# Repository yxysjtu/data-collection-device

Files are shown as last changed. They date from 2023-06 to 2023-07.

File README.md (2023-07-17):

# Datalogger

This is a picture of the device supporting low frequency sensor data-logging with STM32F103RGT6.
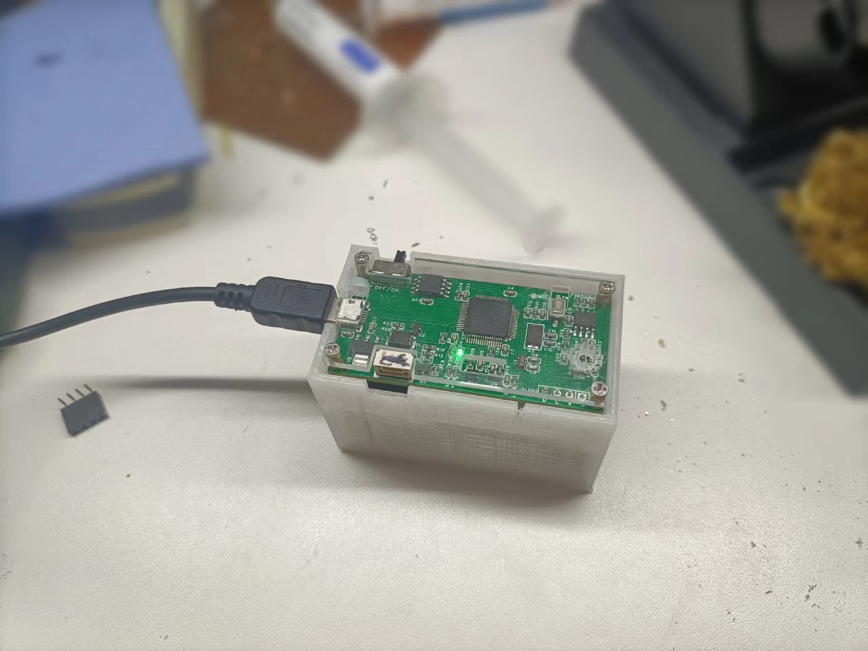
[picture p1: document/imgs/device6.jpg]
 
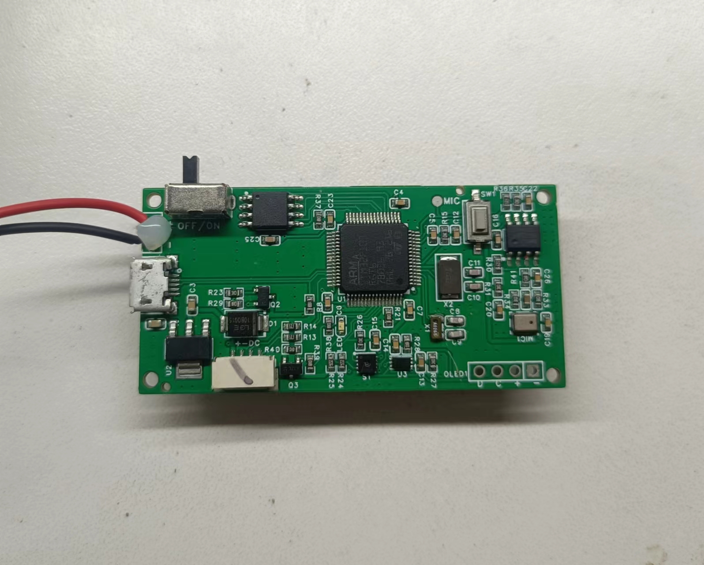
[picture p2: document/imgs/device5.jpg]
 

Core functions:
* periodically collect environment data such as temperature, humidity, light intensity and sound intensity (the sampling period can be configured in software user-interface)
* log data to an external flash (16MB, more than enough memory for 1 year usage)
* provide user-friendly interface to configure the device and retrive data (simulate a USB disk to easily store and get data as files in .csv format, using python script to write configuration info into the device)

Specs:
* 2 AA batteries with 6000h life expectancy. (suppose 50uA in standby mode and 40mA in active mode, the logging time is 2s, 1h sampling period, 1000mAh battery)
* can store up to 45000 records before running out of battery charge
* support measurement of sound(35-100dB), light(0-65535lux), temperature(0-85 degree in celsius), humidity(0-100%)

How to use:
1. Open the switch on the device and it will start periodically collecting data.
2. If you need to configure the time and sampling-period of the device, plug in the micro-usb cable, run config.py and input sampling period. Unplug the cable, and the device will read the configuration info and update its time according to the local time of your computer, the LED will double blink indicating config success, and set up alarm time before going to standby mode.
3. If you need to get the data, plug in the micro-usb cable. The device should be recognized by your computer as USB Mass Storage Device. The data is stored in csv format and you can easily copy it to your computer for further data processing.
4. If the LED is constantly blinking, that is suggesting low battery.

* USB disk interface
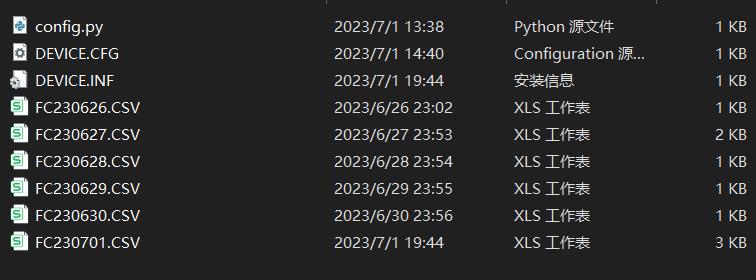
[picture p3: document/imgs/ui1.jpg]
USB disk
 
* Configuration interface
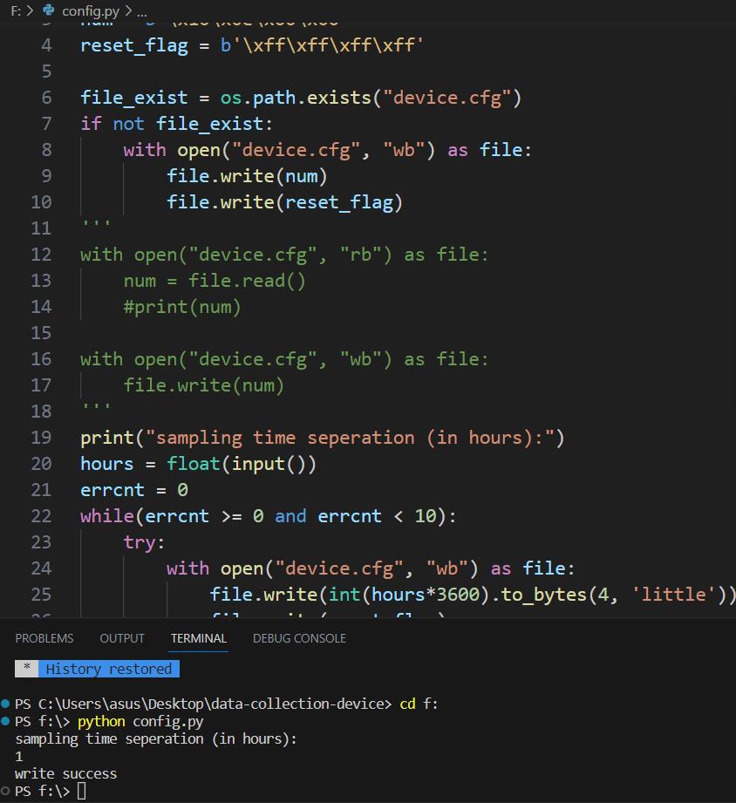
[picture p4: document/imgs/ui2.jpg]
config UI
 
* Data format
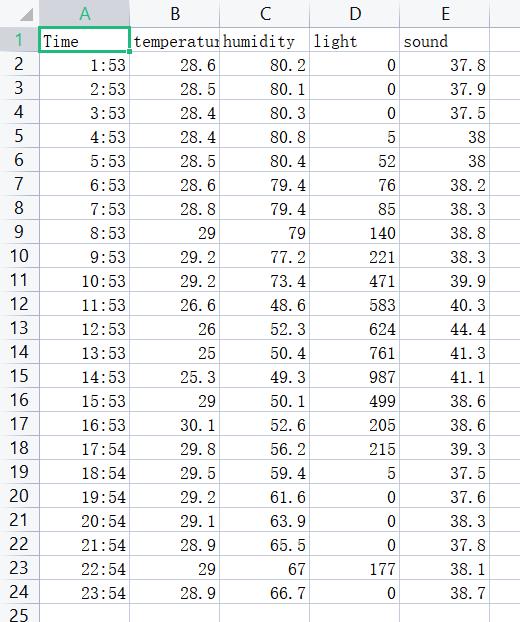
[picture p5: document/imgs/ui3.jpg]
data format
 

## Hardware Design
### Schematic
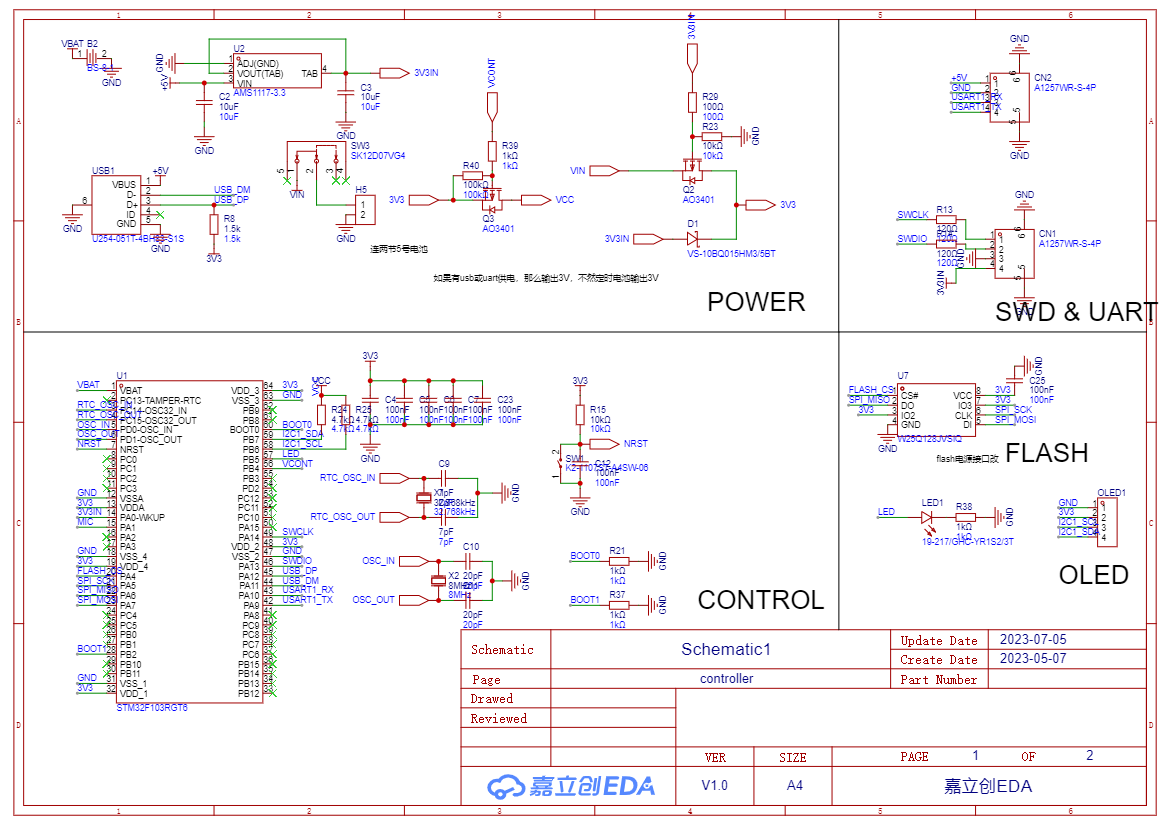
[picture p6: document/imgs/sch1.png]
Controller
 
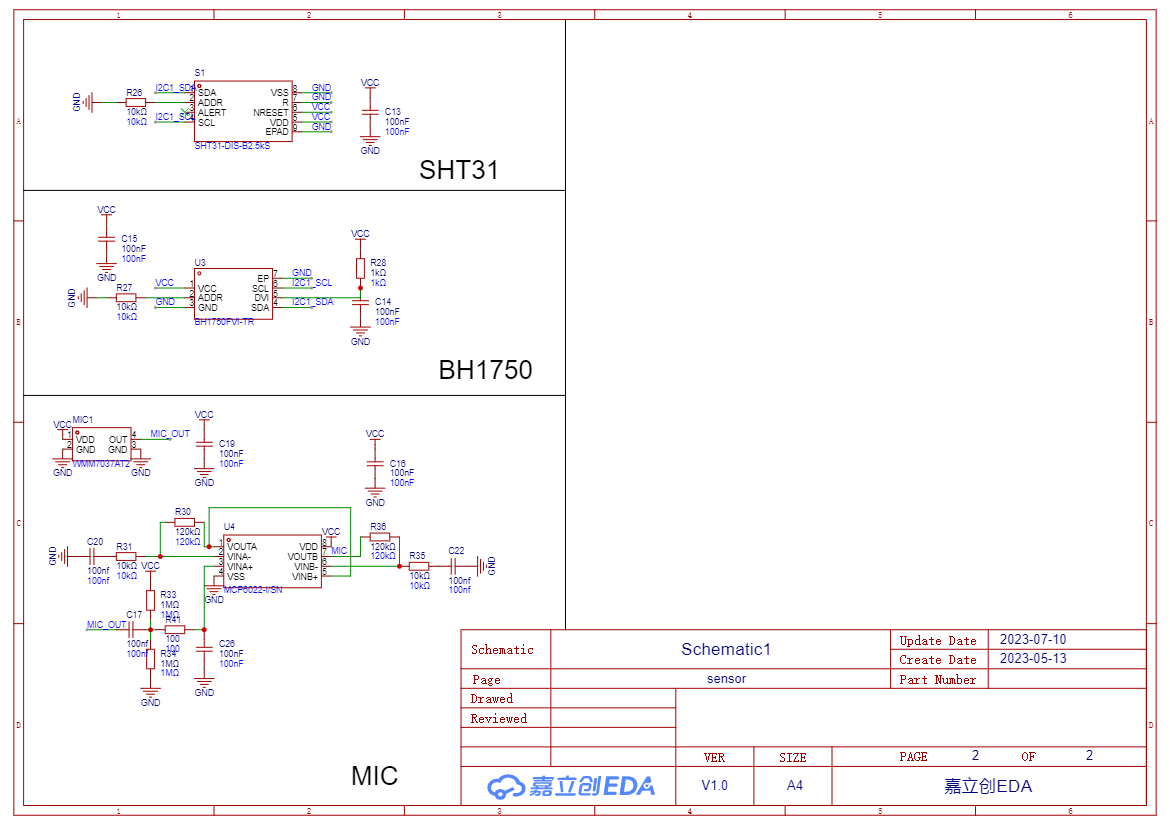
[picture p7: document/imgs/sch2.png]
Sensors
 

(notice: choose 7pf 32.768khz crystal oscillator for stable oscillation)

### PCB
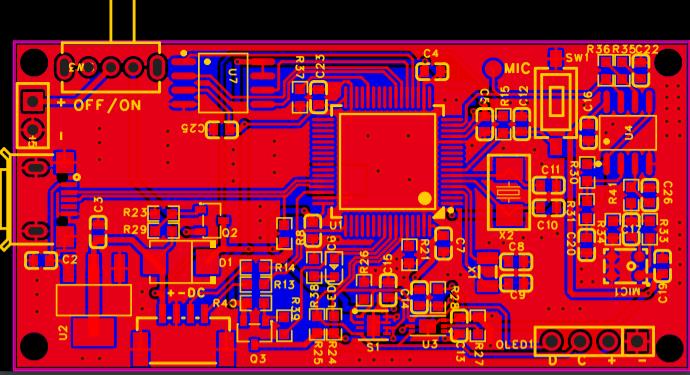
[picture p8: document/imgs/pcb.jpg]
PCB
 

### Mechanical Design
* Front panel using laser cutting PMMA
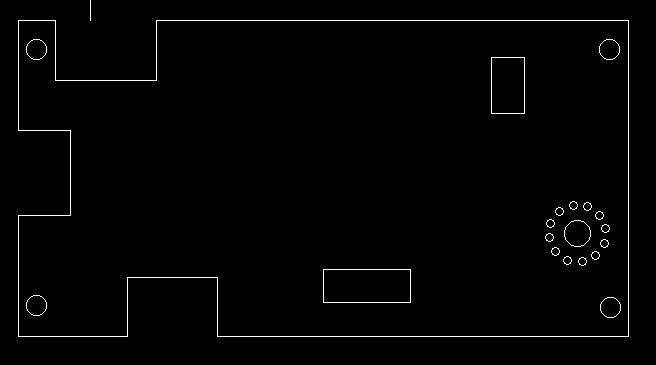
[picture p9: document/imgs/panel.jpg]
panel
 
* 3D printed body part and bottom cover
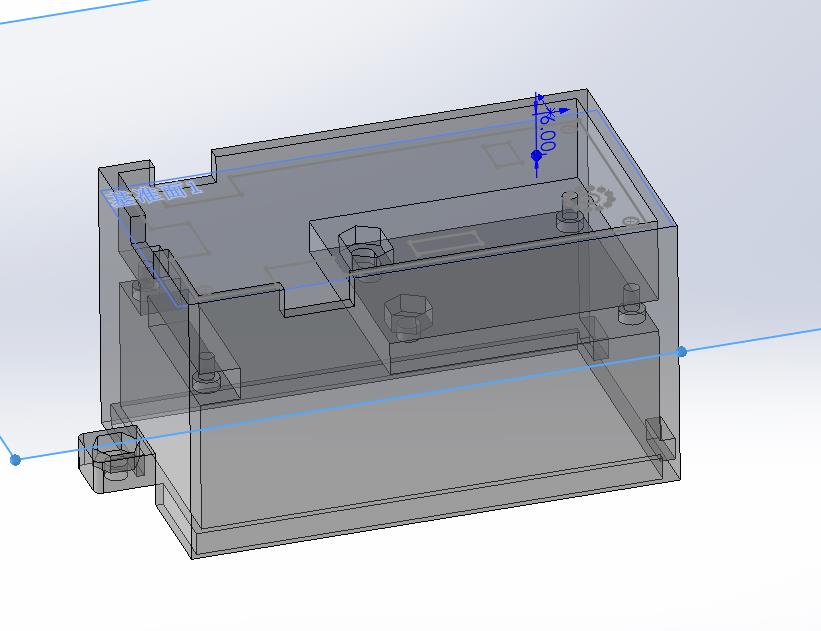
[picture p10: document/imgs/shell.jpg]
body
 
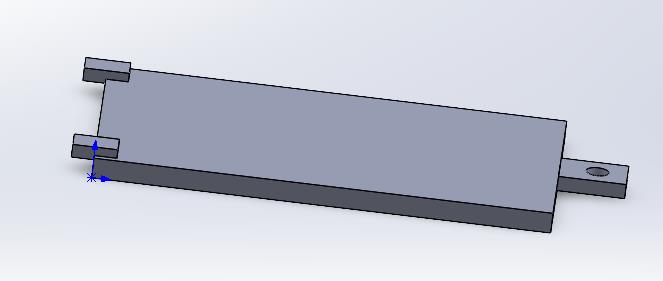
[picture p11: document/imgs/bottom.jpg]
bottom
 

## Firmware
The project is developed using CubeMX and KEIL, using STM32 HAL library.

The main code is in /code/run.h

All custom library is in /code/lib/

The project file is in /firmware/

## Background
For background on / motivation for this project, please see https://opendeved.net/programmes/ilce-in-tanzania/.

Reference: (same project with different design) https://github.com/bablokb/pcb-pico-datalogger#pico-datalogger-with-integrated-power-management

## License
This work is licensed under CC-BY-4.0.

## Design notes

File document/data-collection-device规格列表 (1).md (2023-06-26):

# 定时采样传感器规格列表

### 修订历史
|  | 时间| 备注|
| --- | --- | --- |
| 1 | 2023/6/23 | 添加产品说明与测量精度|
| 2 | 2023/6/26 | 根据实际测量修改产品尺寸，添加实物图片，补充使用方法，加入注意事项 |

### 产品说明
| 名称 | 规格|
| --- | --- |
| 产品尺寸 | 64.8X37.9X38.8 (mm X mm X mm) | 
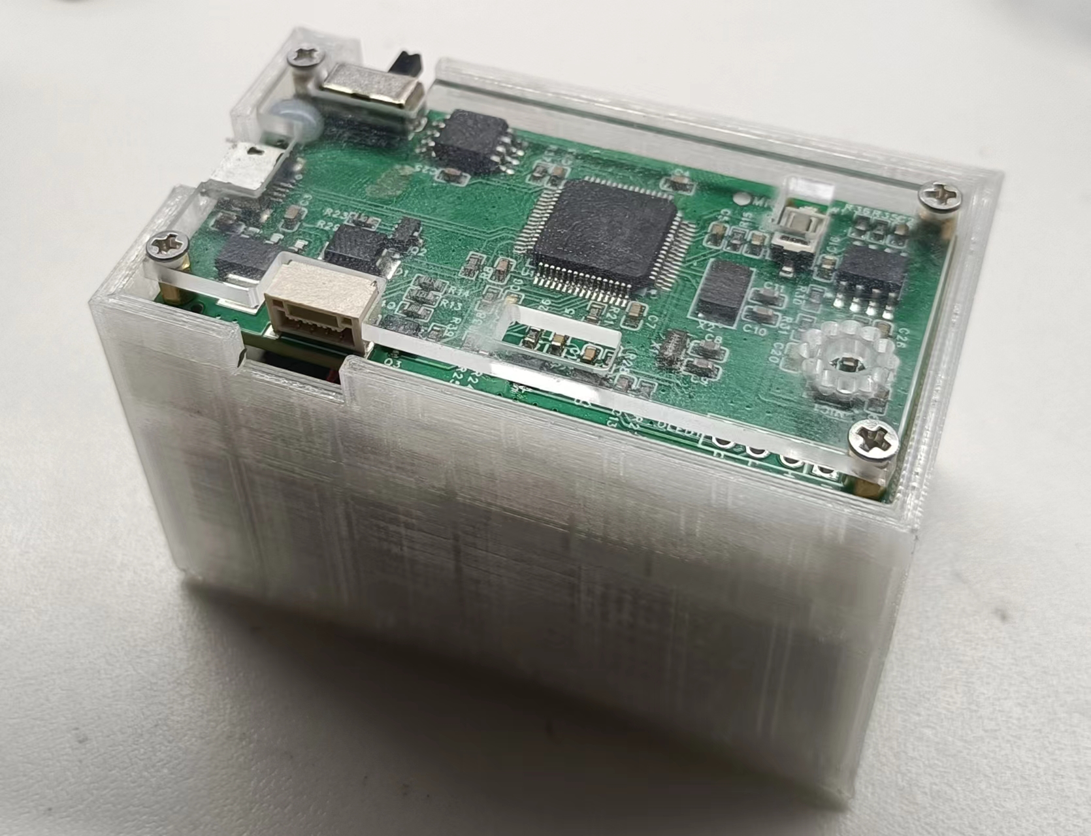
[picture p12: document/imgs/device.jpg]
输入图片说明
| 实物图片 | |
| 电源 | 2节5号电池 + 1节纽扣电池CR2032 |
| 使用寿命 | 6000h（以电池电量800mAh，采样间隔1h计算，平均消耗电量0.133mAh/h）
| 功能 | 以指定频率测量光照，温度，湿度，声强数据，并记录，可以以USB接口读出数据|
| 使用方法 | 初始先用USB线插入电脑，设备作为U盘接入电脑，运行U盘内的config.py(需要电脑已安装python)，输入每几小时采样一次，设备则会存下当前本机时间进行校准设备时间，以及存下采样时间间隔。安装电池，打开开关，设备则会以给定时间间隔进行采样，并把数据以csv的格式进行存储。每日存储一个csv文件，名称为FCyymmdd.CSV，如FC230601.CSV.|
|注意事项| 1.在校准时间成功后设备指示灯会闪烁一下; 2.在电池电压不足时设备指示灯会在USB电源插入后频闪.|

### 测量精度
（实验室环境下测试）
| 指标 | 精度|
| --- | --- |
|光照| +-10% (0~65535lux) |
| 温度 | +-3摄氏度 (0~85度) |
| 湿度 | +-2% (0~100%)|
| 声强 | +-3dB (35~100dB)|

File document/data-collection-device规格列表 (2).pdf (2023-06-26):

# 定时采样传感器规格列表

### 修订历史

| 时间 | 备注
1 | 2023/6/23 | 添加产品说明与测量精度
2 | 2023/6/26 | 根据实际测量修改产品尺⼨，添加实物图⽚，补充使⽤⽅法，加⼊注意事项

### 产品说明

名 称 | 规格
产 品 尺 ⼨ | 64.8X37.9X38.8 (mm X mm X mm)

实
物
图
⽚

电
源

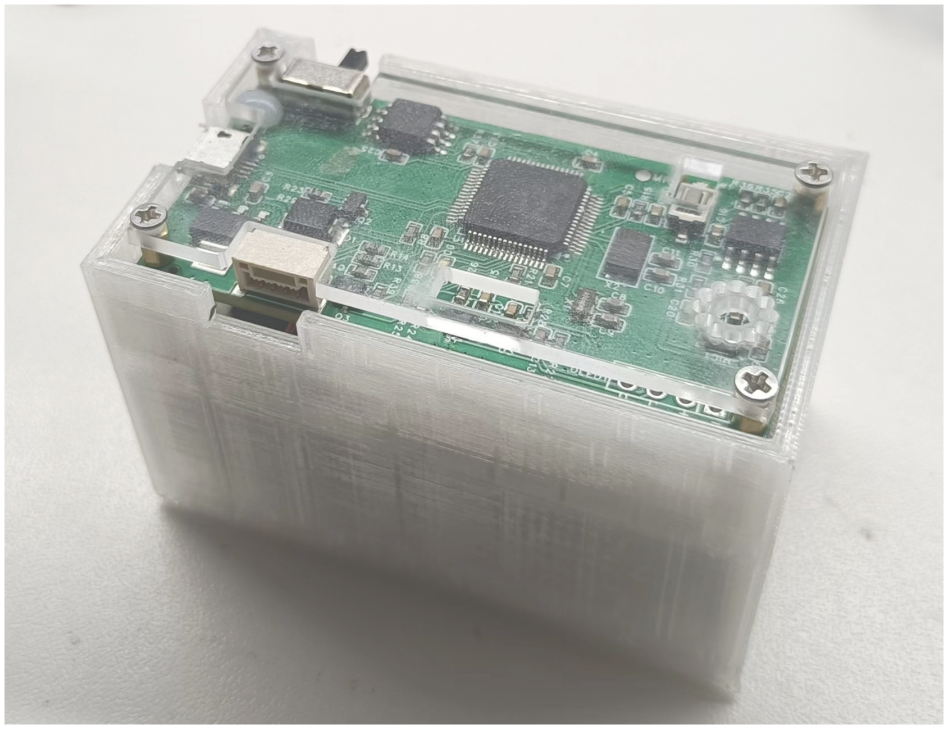
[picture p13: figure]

2节5号电池 + 1节纽扣电池CR2032

名 称 | 规格
使 ⽤ 寿 命 | 6000h（以电池电量800mAh，采样间隔1h计算，平均消耗电量0.133mAh/h）
功 能 | 以指定频率测量光照，温度，湿度，声强数据，并记录，可以以USB接⼝读出数据
使 ⽤ ⽅ 法 | 初始先⽤USB线插⼊电脑，设备作为U盘接⼊电脑，运⾏U盘内的config.py(需要电脑已安装 (http://xn--uconfig-3p9ku36y7xag81lw3s.py) python)，输⼊每⼏⼩时采样⼀次，设备则会存下当前本机时间进⾏校准设备时间，以及存下采样 时间间隔。安装电池，打开开关，设备则会以给定时间间隔进⾏采样，并把数据以csv的格式进⾏ 存储。每⽇存储⼀个csv⽂件，名称为FCyymmdd.CSV，如FC230601.CSV.
注 意 事 项 | 1.在校准时间成功后设备指⽰灯会闪烁⼀下; 2.在电池电压不⾜时设备指⽰灯会在USB电源插⼊后 频闪.

### 测量精度

（实验室环境下测试）

指标 | 精度
光照 | ±10% (0~65535lux)
温度 | ±3摄⽒度 (0~85度)
湿度 | ±2% (0~100%)
声强 | ±3dB (35~100dB)

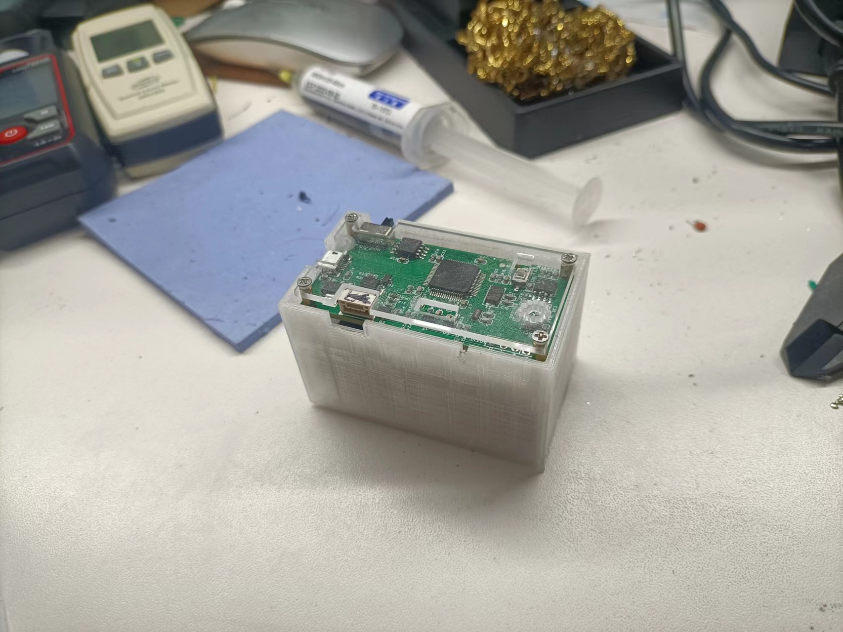
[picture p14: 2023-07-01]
document/imgs/device4.jpg

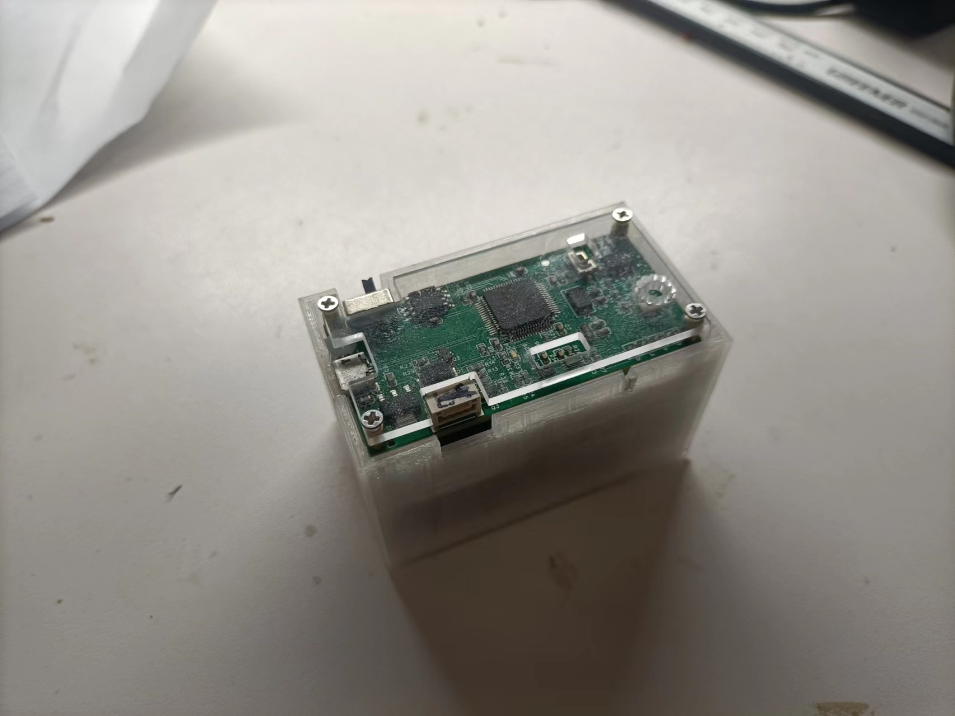
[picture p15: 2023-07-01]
document/imgs/device2.jpg

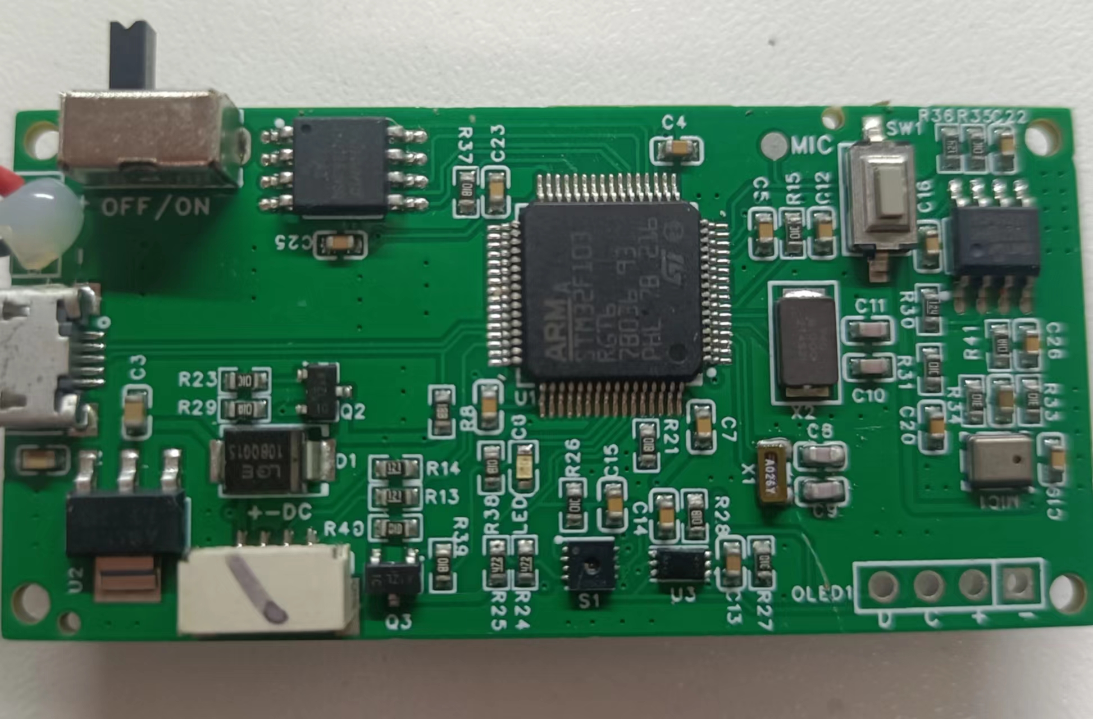
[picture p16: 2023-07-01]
document/imgs/device3.jpg

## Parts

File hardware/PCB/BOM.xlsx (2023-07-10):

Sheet: 电子元件
Item | Comment | Designator | Footprint | Quantity | ManufacturerPart | Manufacturer | 元件编号 | 元器件来源 | 加工方式
厚膜电阻 4.7kΩ ±1% 100mW | 4.7kΩ | R24,R25 | 0603 | 2 | 0603WAF4701T5E | UNI-ROYAL(厚声) | C23162 | 立创商城 | 嘉立创SMT
10uF ±20% 25V | 10uF | C2,C3 | 0603 | 2 | CL10A106MA8NRNC | SAMSUNG(三星) | C96446 | 立创商城 | 嘉立创SMT
电池底座 适用电池:CR2032 镀金 | BS-8-1 | B2 | SMD | 1 | BS-8-1 | Q&J | C70378 | 淘宝 | 自行焊接
MCP6022T-I/SN | MCP6022-I/SN | U4 | SOIC-8 | 1 | MCP6022-I/SN | MICROCHIP(美国微芯) | C57639 | 立创商城 | 嘉立创SMT
P沟道 30V 4A | AO3401 | Q2,Q3 | SOT-23 | 2 | AO3401 | TWGMC(台湾迪嘉) | C15127 | 立创商城 | 嘉立创SMT
15V 1A 320mV@1A | VS-10BQ015HM3/5BT | D1 | SMB | 1 | VS-10BQ015HM3/5BT | VISHAY(威世) | C688900 | 立创商城 | 嘉立创SMT
100nF ±10% 50V | 100nf | C20 | 0603 | 1 | 0603B104K500NT | FH(风华) | C14663 | 立创商城 | 嘉立创SMT
 | 100nF | C26 |  | 1 | 0603B104K500NT | FH(风华) | C14663
 | 100nf | C22 |  | 1 | 0603B104K500NT | FH(风华) | C14663
 | 100nF | C4,C5,C6,C7,C12,C13,C14,C15,C16,C19,C23,C25,C17 |  | 12 | 0603B104K500NT | FH(风华) | C14663
厚膜电阻 1MΩ ±1% 100mW | 1MΩ | R33,R34 | 0603 | 2 | 0603WAF1004T5E | UNI-ROYAL(厚声) | C22935 | 立创商城 | 嘉立创SMT
厚膜电阻 120kΩ ±1% 100mW | 120kΩ | R30,R36 | 0603 | 2 | 0603WAF1203T5E | UNI-ROYAL(厚声) | C25808 | 立创商城 | 嘉立创SMT
厚膜电阻 10kΩ ±1% 100mW | 10kΩ | R15,R23,R26,R27,R31,R35 | 0603 | 6 | 0603WAF1002T5E | UNI-ROYAL(厚声) | C25804 | 立创商城 | 嘉立创SMT
(温湿度传感器)SHT31-DIS-B2.5kS | SHT31-DIS-B2.5kS | S1 | DFN-8-EP(2.5x2.5) | 1 | SHT31-DIS-B2.5kS | Sensirion(瑞士盛思锐) | C80862 | 立创商城 | 嘉立创SMT
厚膜电阻 100kΩ ±1% 100mW | 100kΩ | R40 | 0603 | 1 | 0603WAF1003T5E | UNI-ROYAL(厚声) | C25803 | 立创商城 | 嘉立创SMT
厚膜电阻 100Ω ±1% 100mW | 100 | R41 | 0603 | 1 | 0603WAF1000T5E | UNI-ROYAL(厚声) | C22775 | 立创商城 | 嘉立创SMT
 | 100Ω | R29 |  | 1 | 0603WAF1000T5E | UNI-ROYAL(厚声) | C22775
K2-1107ST-A4SW-06 | K2-1107ST-A4SW-06 | SW1 | SMD | 1 | K2-1107ST-A4SW-06 | 韩国韩荣 | C2837195 | 立创商城 | 嘉立创SMT
(麦克风)MIC 3.76*2.95*1.1 | WMM7037AT2 | MIC1 | LGA-4(3x3.8) | 1 | WMM7037AT2 | WILLSEMI(韦尔) | C140705 | 立创商城 | 嘉立创SMT
W25Q128 | W25Q128JVSIQ | U7 | SOIC-8-208mil | 1 | W25Q128JVSIQ | WINBOND(华邦) | C97521 | 立创商城 | 嘉立创SMT
LED翠绿 | 19-217/GHC-YR1S2/3T | LED1 | 0603 | 1 | 19-217/GHC-YR1S2/3T | EVERLIGHT(亿光) | C72043 | 立创商城 | 嘉立创SMT
Micro-B 母座 卧贴 | U254-051T-4BH83-S1S | USB1 | SMD | 1 | U254-051T-4BH83-S1S | XKBConnectivity(中国星坤) | C319160 | 立创商城 | 嘉立创SMT
8MHz ±10ppm 20pF YSX530GA YSX530GA | 8MHz | X2 | SMD5032-2P | 1 | X50328MSB2GI | YXC(扬兴晶振) | C115962 | 立创商城 | 嘉立创SMT
32.768kHz ±20ppm 7pF | 32.768kHz | X1 | SMD3215-2P | 1 | FC-12M32.768KHZ7PF20PPM | EPSON(爱普生) | C99009 | 立创商城 | 嘉立创SMT
厚膜电阻 1kΩ ±1% 100mW | 1kΩ | R21,R28,R37,R38,R39 | 0603 | 5 | 0603WAF1001T5E | UNI-ROYAL(厚声) | C21190 | 立创商城 | 嘉立创SMT
20pF ±5% 50V | 20pF | C10,C11 | 0603 | 2 | CL10C200JB8NNNC | SAMSUNG(三星) | C1648 | 立创商城 | 嘉立创SMT
STM32F103RGT6 | STM32F103RGT6 | U1 | LQFP-64(10x10) | 1 | STM32F103RGT6 | ST(意法半导体) | C8317 | 淘宝邮寄嘉立创 | 嘉立创SMT
1.25mm 1x4P 卧贴 GH1.25间距卧式贴片 4P 连接器 | A1257WR-S-4P | CN1 | SMD,P=1.25mm | 1 | A1257WR-S-4P | CJT(长江连接器) | C2998792 | 立创商城 | 嘉立创SMT
3脚2二档位SK12D07VG4滑动开关1P2T卧式拨动开关 【拨动】 | SK12D07VG4 | SW3 | 插件 | 1 | SK12D07VG4 | SHOUHAN(首韩) | C393937 | 立创商城 | 嘉立创SMT
7pF 50V ±0.25pF | 7pF | C8,C9 | 0603 | 2 | 0603CG7R0C500NT | FH(风华) | C1682 | 立创商城 | 嘉立创SMT
输出3.3V 1A | AMS1117-3.3 | U2 | SOT-223-3 | 1 | AMS1117-3.3 | UMW(广东友台半导体) | C6186 | 立创商城 | 嘉立创SMT
厚膜电阻 1.5kΩ ±1% 100mW | 1.5k | R8 | 0603 | 1 | 0603WAF4701T5E | UNI-ROYAL(厚声) | C22843 | 立创商城 | 嘉立创SMT
(光照传感器)BH1750FVI-TR | BH1750FVI-TR | U3 | WSOF-6 | 1 | BH1750FVI-TR | ROHM(罗姆) | C78960 | 立创商城 | 嘉立创SMT
厚膜电阻 120Ω ±1% 100mW | 120Ω | R13,R14 | 0603 | 2 | 0603WAF1200T5E | UNI-ROYAL(厚声) | C22787 | 立创商城 | 嘉立创SMT

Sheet: 机械零部件
Item | Comment | Quantity
沉头十字螺丝 M3*8 | M3*8 | 2
六角螺母 M3 | M3 | 2
单头六角铜螺柱 M2*6+3 | M2*6+3 | 4
双通六角铜柱 M2*3 | M2*3 | 4
沉头十字螺丝 M2*4 | M2*4 | 4
沉头十字螺丝 M2*8 | M2*8 | 4
3D打印外壳 |  | 1
3D打印电池后盖 |  | 1
电池盒 | 2节5号电池 | 1
亚克力上盖 |  | 1
5号电池 |  | 2

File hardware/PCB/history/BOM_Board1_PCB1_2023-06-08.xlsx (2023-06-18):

No. | Quantity | Comment | Designator | Footprint | Value | Manufacturer Part | Manufacturer | Supplier Part | Supplier
1 | 1 | BS-8-1 | B2 | BAT-TH_BS-8-1 |  | BS-8-1 | Q&J | C70378 | LCSC
2 | 2 | 10uF | C2,C3 | C0603 | 10uF | CL10A106MA8NRNC | SAMSUNG(三星) | C96446 | LCSC
3 | 12 | 100nF | C4,C5,C6,C7,C12,C13,C14,C15,C16,C19,C23,C25 | C0603 | 100nF | 0603B104K500NT | FH(风华) | C30926 | LCSC
4 | 2 | 12pF | C8,C9 | C0603 | 12pF | CC0603JRNPO9BN120 | YAGEO(国巨) | C107034 | LCSC
5 | 2 | 20pF | C10,C11 | C0603 | 20pF | CL10C200JB8NNNC | SAMSUNG(三星) | C1648 | LCSC
6 | 1 | 1uF | C17 | C0603 | 1uF | CL10A105KB8NNNC | SAMSUNG(三星) | C15849 | LCSC
7 | 1 | 100nf | C20 | C0603 | 100nf | 0603B104K500NT | FH(风华) |  | LCSC
8 | 1 | 100nf | C22 | C0603 | 100nf | 0603B104K500NT | FH(风华) | C30926 | LCSC
9 | 1 | 100nF | C26 | C0603 | 100nF
10 | 1 | A1257WR-S-4P | CN1 | CONN-SMD_A1257WR-S-4P |  | A1257WR-S-4P | CJT(长江连接器) | C225127 | LCSC
11 | 1 | VS-10BQ015HM3/5BT | D1 | SMB_L4.6-W3.6-LS5.3-RD |  | VS-10BQ015HM3/5BT | VISHAY(威世) | C413465 | LCSC
12 | 1 |  | H5 | HDR-TH_2P-P2.54-V-F |  |  |  | C49661
13 | 1 | 19-217/GHC-YR1S2/3T | LED1 | LED0603-RD |  | 19-217/GHC-YR1S2/3T | EVERLIGHT(亿光) | C72043 | LCSC
14 | 1 | WMM7037AT2 | MIC1 | MIC-SMD_L3.8-W3.00-TL |  | WMM7037AT2 | WILLSEMI(韦尔) | C140705 | LCSC
15 | 1 |  | OLED1 | HDR-TH_4P-P2.54-V-F |  |  |  | C2718488
16 | 2 | AO3401 | Q2,Q3 | SOT-23-3_L2.9-W1.4-P1.90-LS2.6-BR |  | AO3401 | TWGMC(台湾迪嘉) | C727156 | LCSC
17 | 1 | 1.5k | R8 | R0603 | 1.5k | 0603WAF4701T5E | UNI-ROYAL(厚声) |  | LCSC
18 | 2 | 120Ω | R13,R14 | R0603 | 120Ω | 0603WAF1200T5E | UNI-ROYAL(厚声) | C22787 | LCSC
19 | 6 | 10kΩ | R15,R23,R26,R27,R31,R35 | R0603 | 10kΩ | 0603WAF1002T5E | UNI-ROYAL(厚声) | C25804 | LCSC
20 | 5 | 1kΩ | R21,R28,R37,R38,R39 | R0603 | 1kΩ | 0603WAF1001T5E | UNI-ROYAL(厚声) | C21190 | LCSC
21 | 2 | 4.7kΩ | R24,R25 | R0603 | 4.7kΩ | 0603WAF4701T5E | UNI-ROYAL(厚声) | C23162 | LCSC
22 | 1 | 100Ω | R29 | R0603 | 100Ω | 0603WAF1000T5E | UNI-ROYAL(厚声) | C22775 | LCSC
23 | 2 | 120kΩ | R30,R36 | R0603 | 120kΩ | 0603WAF1203T5E | UNI-ROYAL(厚声) | C25808 | LCSC
24 | 2 | 1MΩ | R33,R34 | R0603 | 1MΩ | 0603WAF1004T5E | UNI-ROYAL(厚声) | C22935 | LCSC
25 | 1 | 100kΩ | R40 | R0603 | 100kΩ | 0603WAF1003T5E | UNI-ROYAL(厚声) | C25803 | LCSC
26 | 1 | 100 | R41 | R0603 | 100
27 | 1 | SHT31-DIS-B2.5kS | S1 | DFN-8_L2.5-W2.5-P0.50-BL-EP |  | SHT31-DIS-B2.5kS | Sensirion(瑞士盛思锐) | C80862 | LCSC
28 | 1 | K2-1107ST-A4SW-06 | SW1 | SW-SMD_L6.1-W3.6-LS7.9 |  | K2-1107ST-A4SW-06 | 韩国韩荣 | C2837195 | LCSC
29 | 1 | SK12D07VG4 | SW3 | SW-TH_SK12D07VG4 |  | SK12D07VG4 | SHOU HAN(首韩) | C393937 | LCSC
30 | 1 | STM32F103RGT6 | U1 | LQFP-64_L10.0-W10.0-P0.50-LS12.0-BL |  | STM32F103RGT6 | ST(意法半导体) | C8317 | LCSC
31 | 1 | AMS1117-3.3 | U2 | SOT-223-4_L6.5-W3.5-P2.30-LS7.0-BR |  | AMS1117-3.3 | UMW(广东友台半导体) | C347222 | LCSC
32 | 1 | BH1750FVI-TR | U3 | WSOF-6_L2.6-W1.6-P0.50-TL-EP |  | BH1750FVI-TR | ROHM(罗姆) | C78960 | LCSC
33 | 1 | MCP6022-I/SN | U4 | SOIC-8_L4.9-W3.9-P1.27-LS6.0-BL |  | MCP6022-I/SN | MICROCHIP(美国微芯) | C34047 | LCSC
34 | 1 | W25Q128JVSIQ | U7 | SOIC-8_L5.3-W5.3-P1.27-LS8.0-BL |  | W25Q128JVSIQ | WINBOND(华邦) | C97521 | LCSC
35 | 1 | U254-051T-4BH83-S1S | USB1 | MICRO-USB-SMD_U254-051T-4BH83-S1S |  | U254-051T-4BH83-S1S | XKB Connectivity(中国星坤) | C319160 | LCSC
36 | 1 | 32.768kHz | X1 | FC-135R_L3.2-W1.5 | 32.768kHz | Q13FC1350000400 | EPSON(爱普生) | C32346 | LCSC
37 | 1 | 8MHz | X2 | CRYSTAL-SMD_L5.0-W3.2 | 8MHz | X50328MSB2GI | YXC(扬兴晶振) | C115962 | LCSC

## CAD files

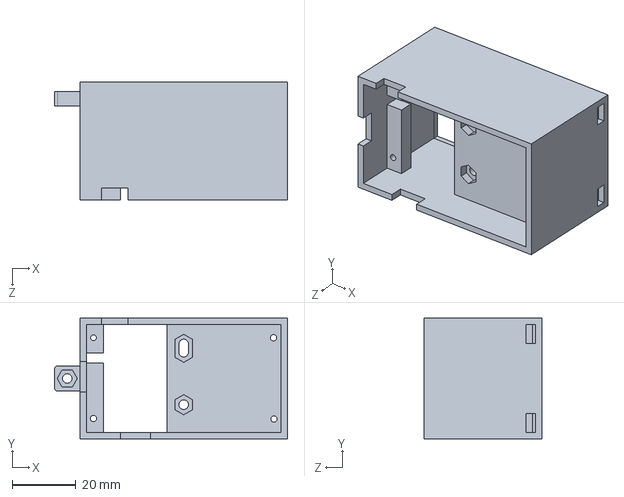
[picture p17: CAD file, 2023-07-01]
hardware/mechanical/history/壳子4.SLDPRT
73.3 x 38.0 x 37.0 mm

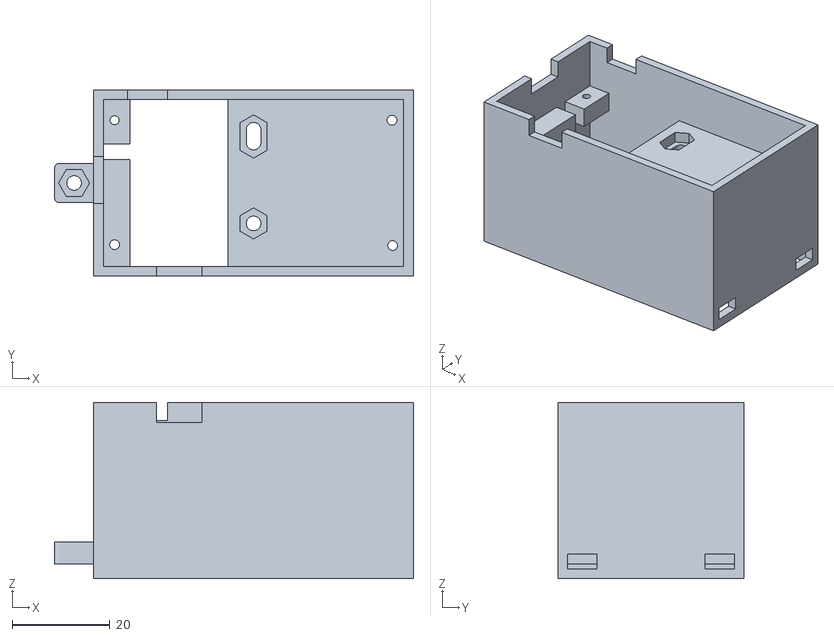
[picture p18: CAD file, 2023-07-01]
hardware/mechanical/壳子5.STL
73.3 x 38.0 x 36.0

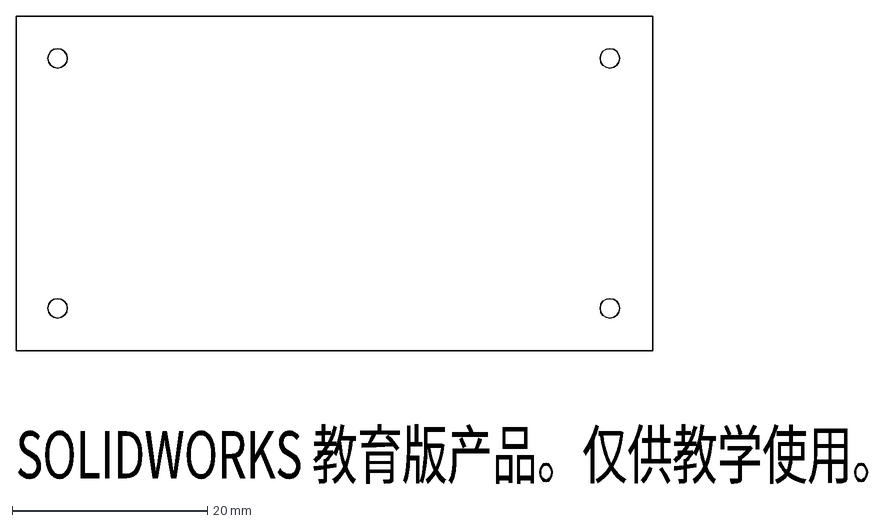
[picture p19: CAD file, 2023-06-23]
hardware/PCB/history/bottom.DXF
SOLIDWORKS 教育版产品。仅供教学使用。

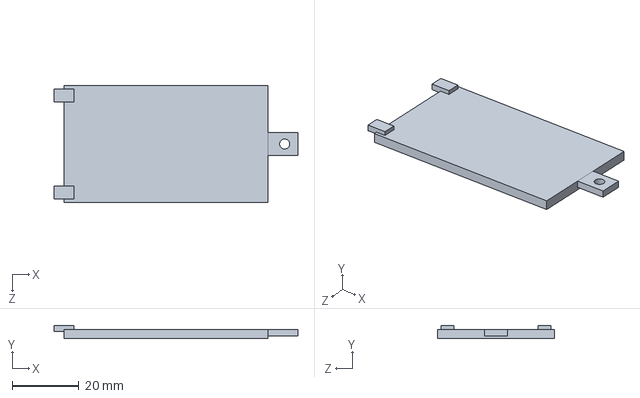
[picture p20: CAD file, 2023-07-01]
hardware/mechanical/history/电池盖2.SLDPRT
73.0 x 4.00 x 35.0 mm

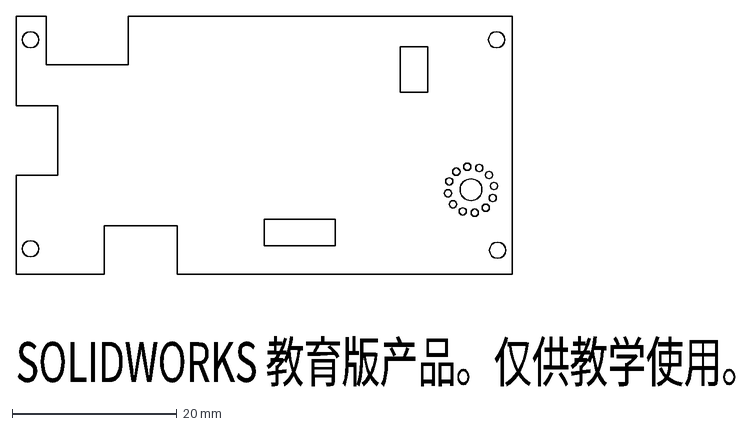
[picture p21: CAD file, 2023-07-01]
hardware/mechanical/top5.DXF
SOLIDWORKS 教育版产品。仅供教学使用。

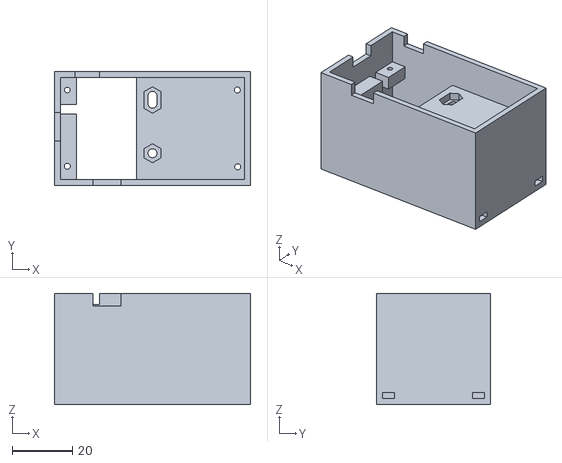
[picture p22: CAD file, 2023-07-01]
hardware/mechanical/history/壳子4变高.STL
65.3 x 38.0 x 37.0

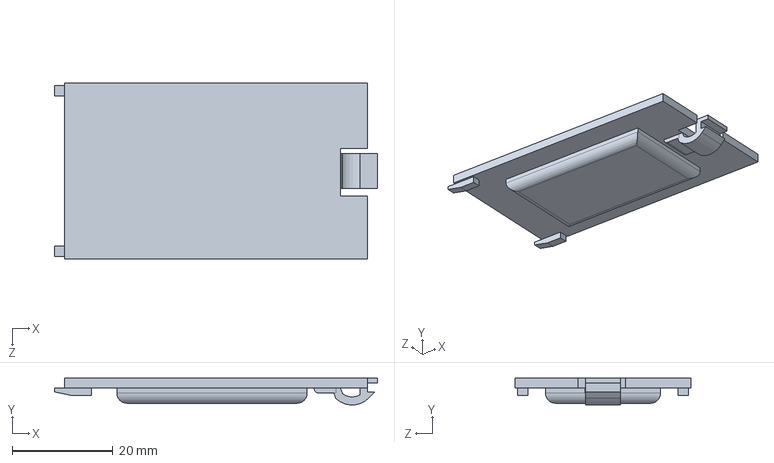
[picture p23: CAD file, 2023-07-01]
hardware/mechanical/history/电池盖.SLDPRT
64.0 x 5.32 x 34.8 mm

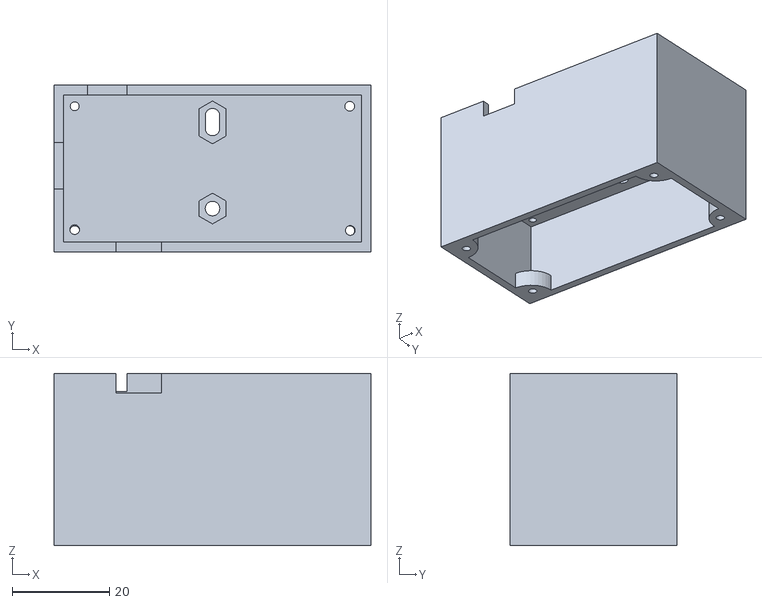
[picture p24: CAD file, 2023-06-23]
hardware/mechanical/history/壳子.STL
65.3 x 34.3 x 35.5

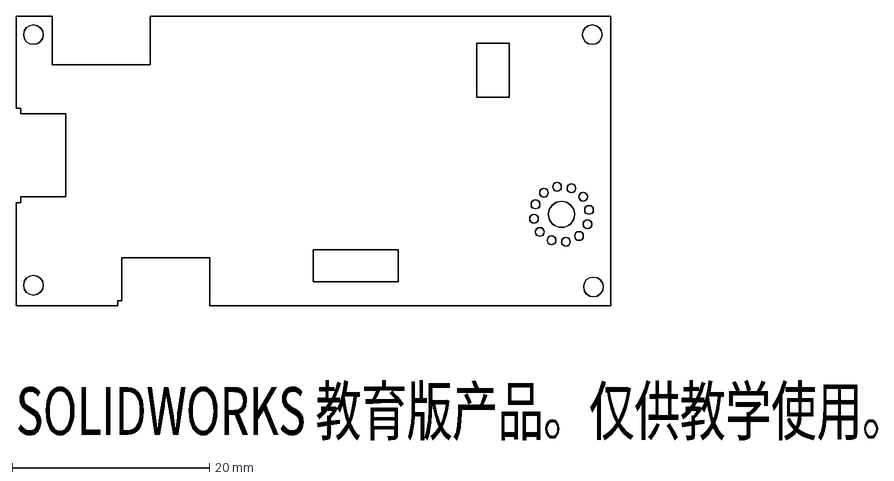
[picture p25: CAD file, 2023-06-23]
hardware/mechanical/history/top4.DXF
SOLIDWORKS 教育版产品。仅供教学使用。

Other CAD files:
hardware/mechanical/电池盖3.STL
hardware/mechanical/history/壳子4高.STL
hardware/mechanical/history/壳子3.SLDPRT
hardware/mechanical/history/电池盖2变高.STL
hardware/mechanical/history/壳子2.SLDPRT
hardware/mechanical/history/壳子2.STL
hardware/mechanical/history/壳子3.STL
hardware/mechanical/history/壳子4.STL
hardware/mechanical/history/电池盖.STL
hardware/mechanical/history/电池盖2.STL

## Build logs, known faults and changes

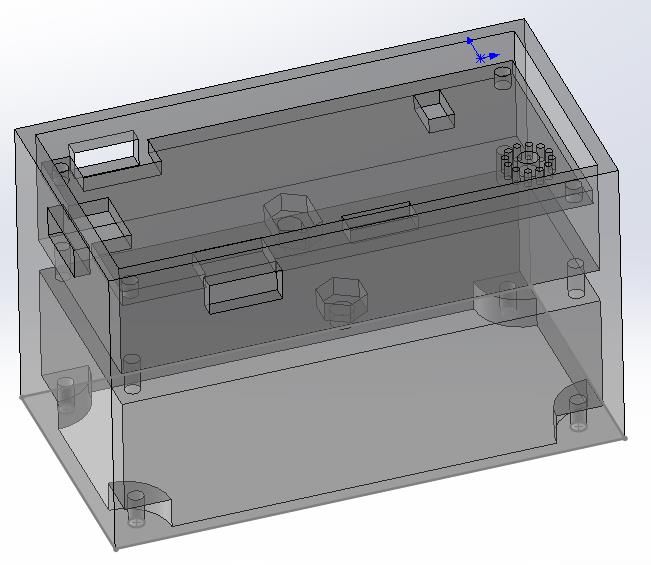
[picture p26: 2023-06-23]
hardware/mechanical/history/3d模型.jpg

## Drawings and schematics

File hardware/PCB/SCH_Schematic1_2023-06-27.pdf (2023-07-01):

## +5V⁺⁵V

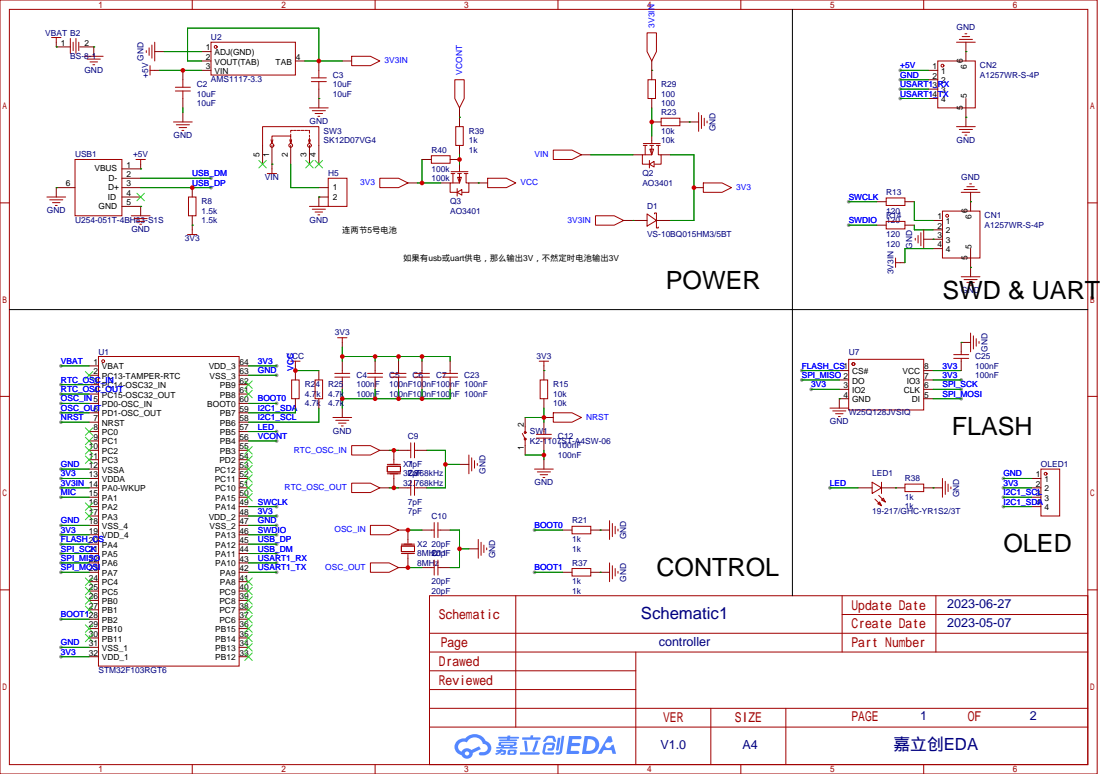
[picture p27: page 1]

# SHT31

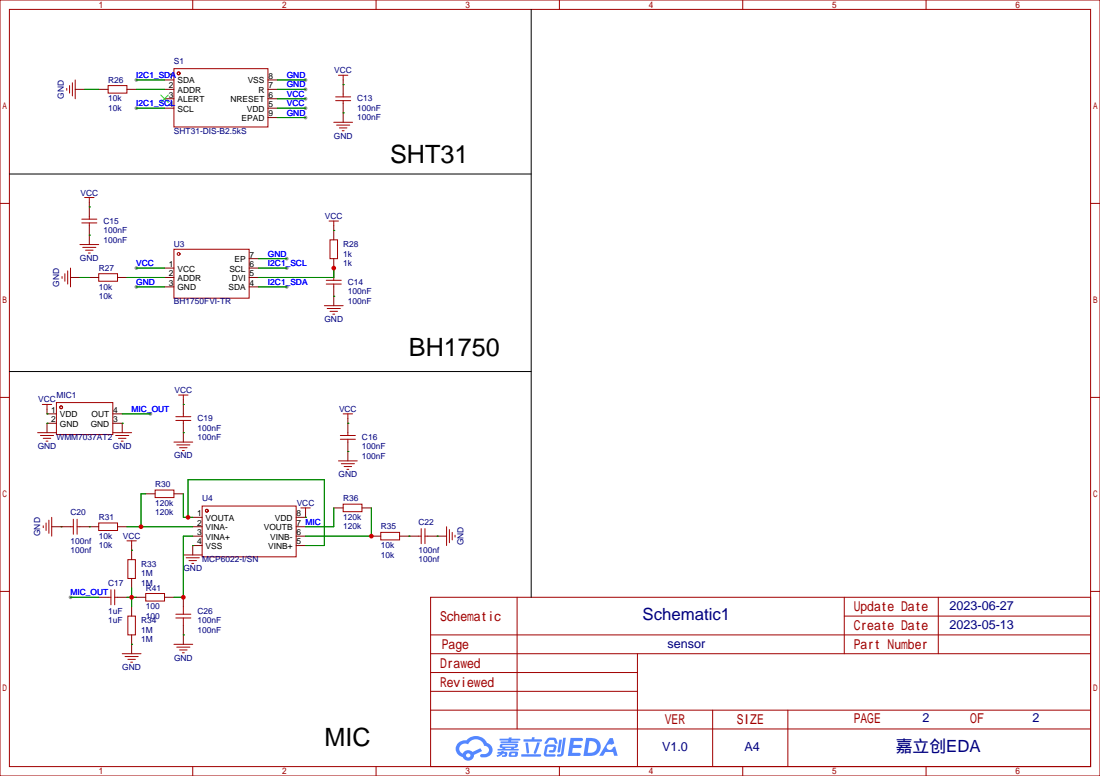
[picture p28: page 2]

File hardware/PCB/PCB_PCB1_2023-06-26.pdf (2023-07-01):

# MIC OFF/ON

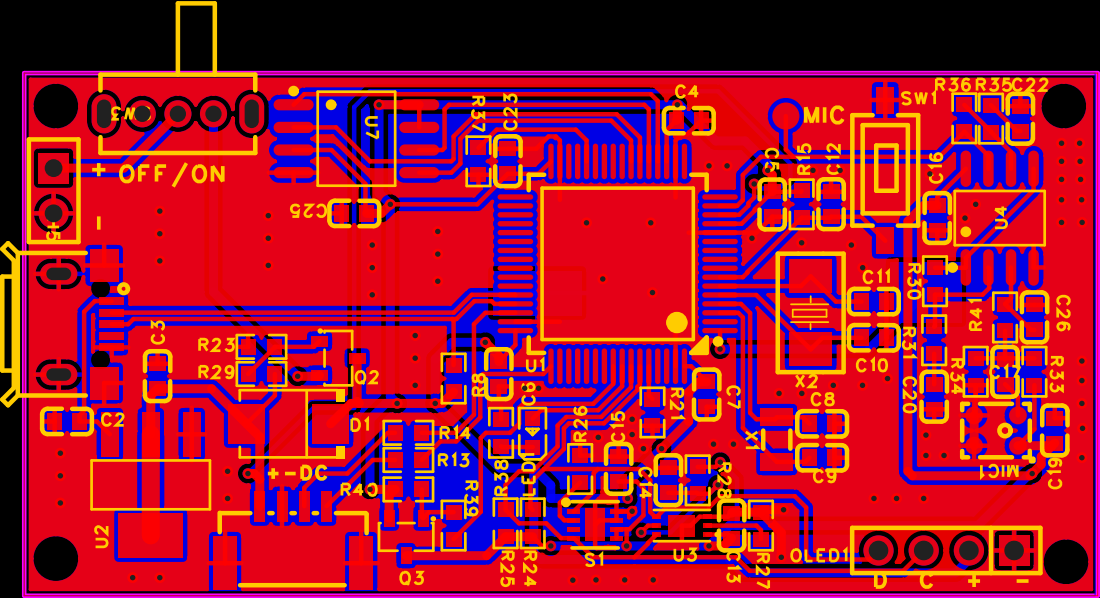
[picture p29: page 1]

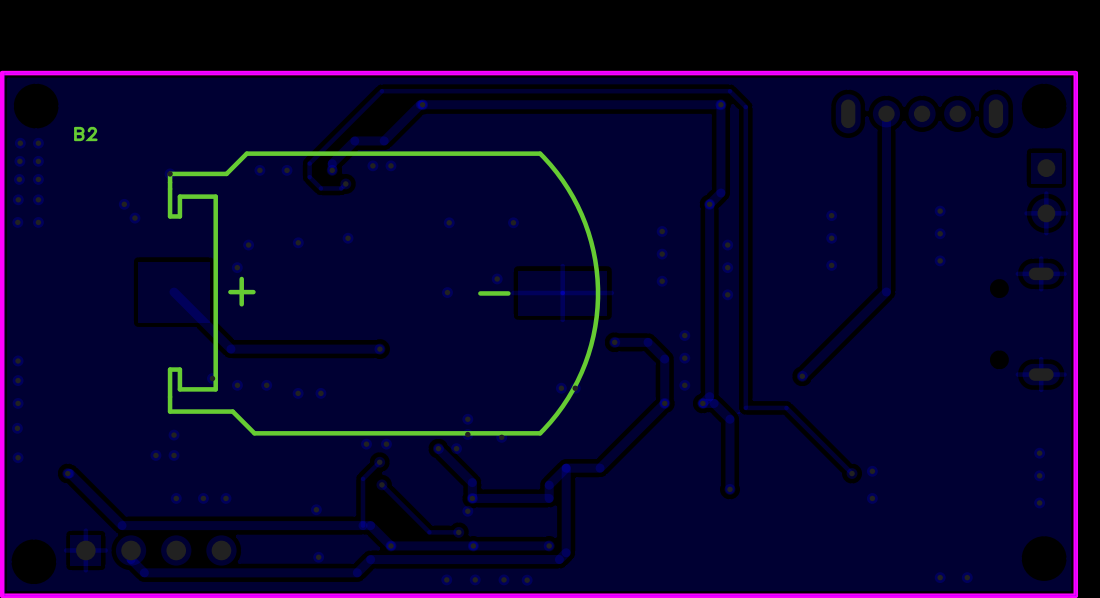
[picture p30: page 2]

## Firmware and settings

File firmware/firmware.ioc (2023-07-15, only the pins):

Mcu.UserName=STM32F103RGTx
PA0-WKUP.Signal=SYS_WKUP
PA1.Signal=ADCx_IN1
PA10.Signal=USART1_RX
PA11.Signal=USB_DM
PA12.Signal=USB_DP
PA13.Signal=SYS_JTMS-SWDIO
PA14.Signal=SYS_JTCK-SWCLK
PA4.GPIO_Label=FLASH_CS
PA4.Signal=GPIO_Output
PA5.Signal=SPI1_SCK
PA6.Signal=SPI1_MISO
PA7.Signal=SPI1_MOSI
PA9.Signal=USART1_TX
PB4.GPIO_Label=VCONT
PB4.Signal=GPIO_Output
PB5.GPIO_Label=LED
PB5.Signal=GPIO_Output
PB6.Signal=I2C1_SCL
PB7.Signal=I2C1_SDA
PC14-OSC32_IN.Signal=RCC_OSC32_IN
PC15-OSC32_OUT.Signal=RCC_OSC32_OUT
PD0-OSC_IN.Signal=RCC_OSC_IN
PD1-OSC_OUT.Signal=RCC_OSC_OUT

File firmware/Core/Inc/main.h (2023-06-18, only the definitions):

#define FLASH_CS_Pin GPIO_PIN_4
#define FLASH_CS_GPIO_Port GPIOA
#define VCONT_Pin GPIO_PIN_4
#define VCONT_GPIO_Port GPIOB
#define LED_Pin GPIO_PIN_5
#define LED_GPIO_Port GPIOB

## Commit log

2023-05-12 差不多功能测试完了
2023-05-22 定时采样
2023-06-03 spi flash 16M
2023-06-18 LSE好像还是不行
    [BOM_Board1_PCB1_2023-06-08.xlsx, PickAndPlace_PCB1_2023-06-08.xlsx]
2023-06-18 初版，去lse
2023-06-20 加入看门狗
2023-06-23 去看门狗，因为看门狗会导致重启
    [bottom.DXF, top4.DXF, 壳子.STL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]
2023-06-26 整理文档
    加入规格列表
    [HAL.OBJ, SD.OBJ, STARTUP.OBJ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]
2023-07-01 flash读写冲突待改
    [BOM.xlsx, FC230623.CSV, FC230624.CSV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]
2023-07-01 final wrap up
    [BOM_Board1_PCB1_2023-05-26.xlsx, BOM_Board1_PCB1_2023-06-05.xlsx, BOM_Board1_PCB1_2023-06-08.xlsx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]
2023-07-10 code cleanup and change hardware design
    In the powerup process, the mic output waveform will rise up to 1.5 dc voltage in 1sec due to input high pass filter. To improve the speed, I change the capacitor from 1uf to 100nf, result in 400ms r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
    [BOM.xlsx, PickAndPlace_PCB1_2023-06-08.xlsx, device.cfg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]
2023-07-15 改mic输入电容100nf，重新校对，加入电池电量监测到csv

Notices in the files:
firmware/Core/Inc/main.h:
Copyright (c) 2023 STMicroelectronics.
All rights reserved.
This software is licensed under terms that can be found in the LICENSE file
